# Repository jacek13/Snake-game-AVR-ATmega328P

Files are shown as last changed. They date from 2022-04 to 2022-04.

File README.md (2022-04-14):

# **Snake game on AVR**

The aim of my project was to create a device that allows you to play the popular game `"Snake"`. I completed the project as part of a university subject. While creating it, I used my original snake game written in C++ for Windows (graphics shown in the command line). I was prototyping the Arduino version. Then I rewritten the whole project into C language on the AVR microcontroller (ATmega328P). 

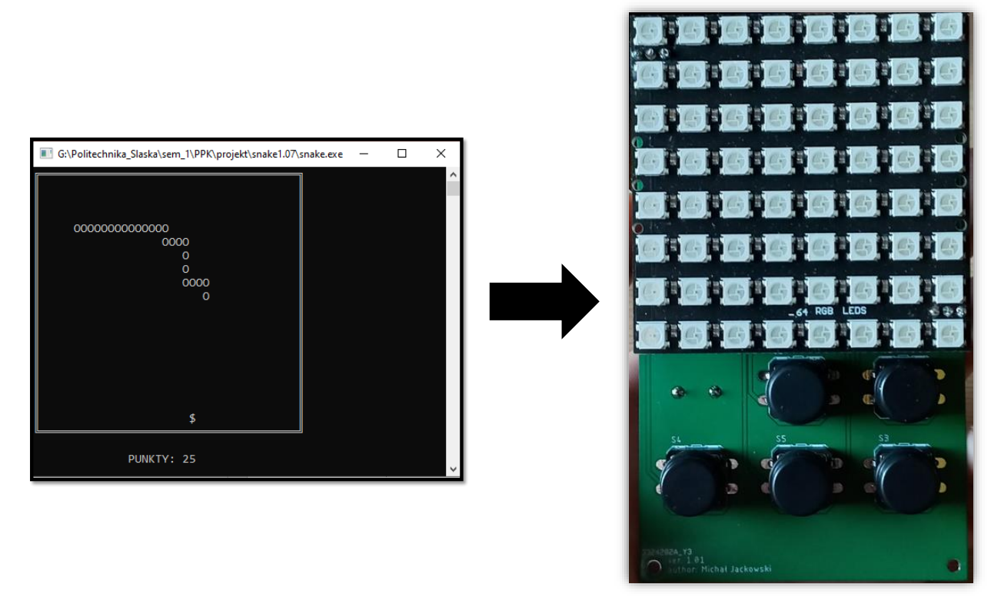
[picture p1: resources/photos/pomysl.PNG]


# **Game Demo**

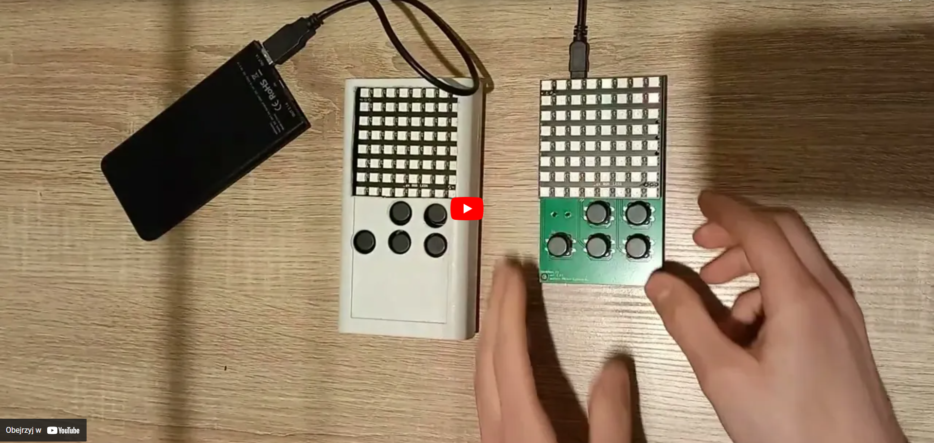
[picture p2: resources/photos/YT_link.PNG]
IMAGE_LINK (https://youtu.be/W63zcMBPLeU)


# **Elements used in the project:**
* RGB matrix 8 x 8 WS2812B
* 5 microswitches
* Buzzer HCM1206X
* ATmega328P
* USB as power supply
* custom board (All eagle files is in resources folder)
* necessary RC elements (all information about values is in the schematics)

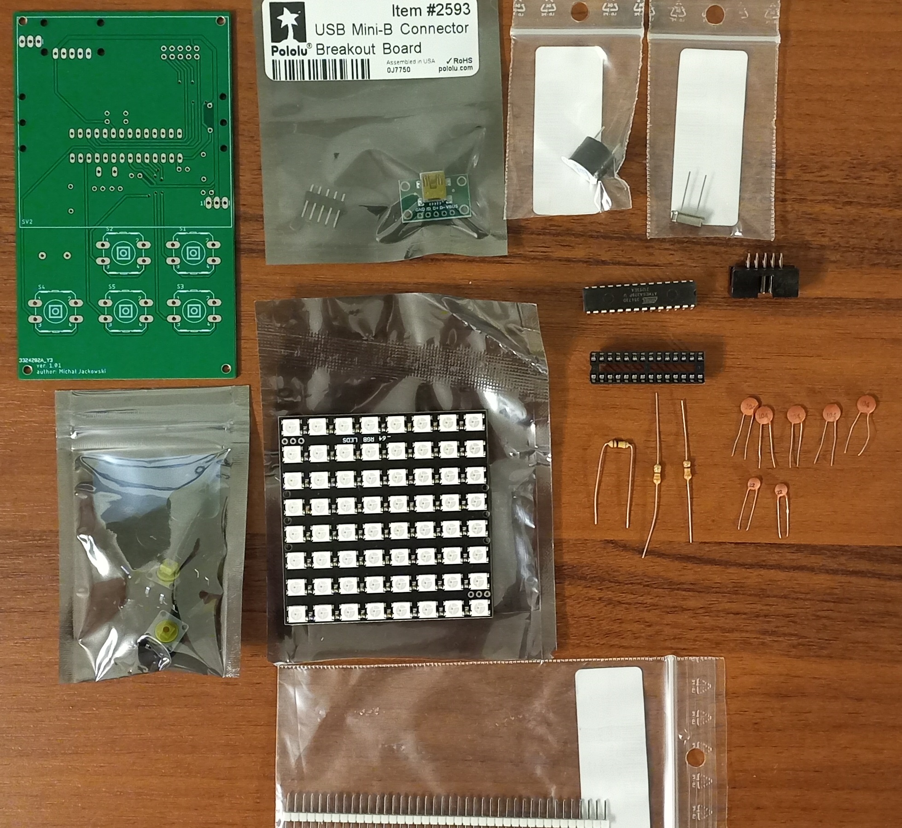
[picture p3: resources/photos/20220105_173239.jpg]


# **PCB**

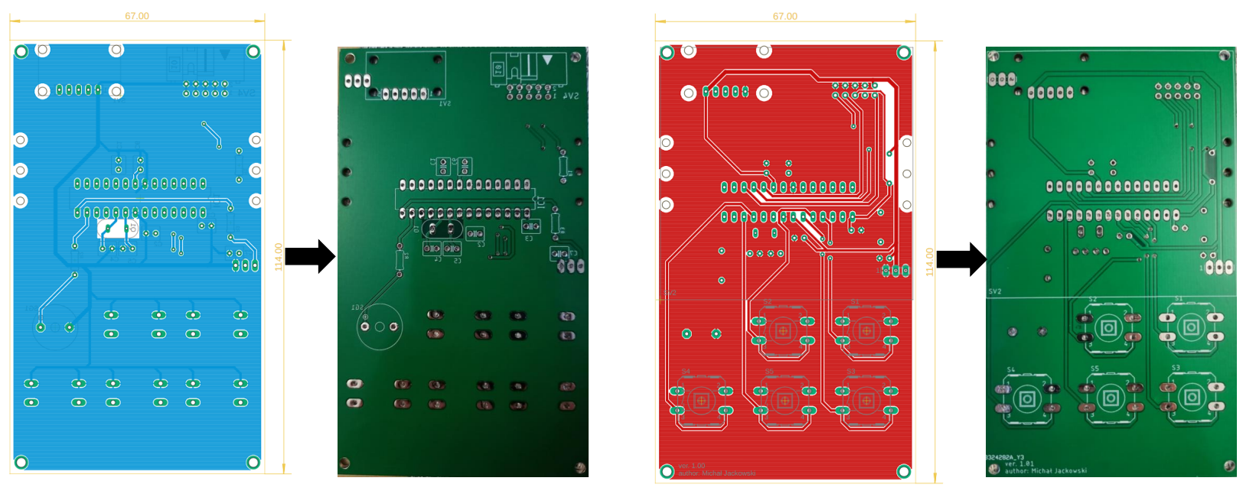
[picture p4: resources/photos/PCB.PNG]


# **IMPORTANT**

in the resources folder there are hex files for both versions of the project (Arduino and AVR). Please note that the AVR version only works for frequencies based on the internal RC oscillator (Set fuse bits on 8Mhz). The prototype version from arduino uses an external crystal oscillator (then you have to change the fuse bits to the external 16 MHz clock). This limitation is due to the [**`light_ws2812`**](https://github.com/cpldcpu/light_ws2812) library that I am using in the project.

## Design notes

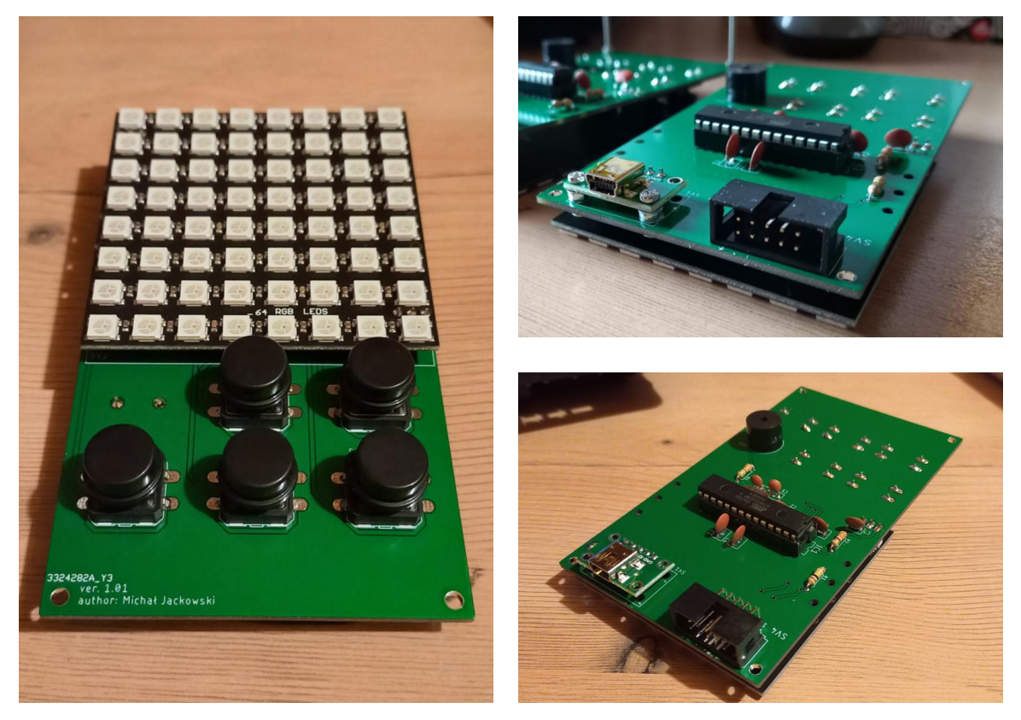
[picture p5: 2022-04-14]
resources/photos/kombinacja_zdjec.PNG

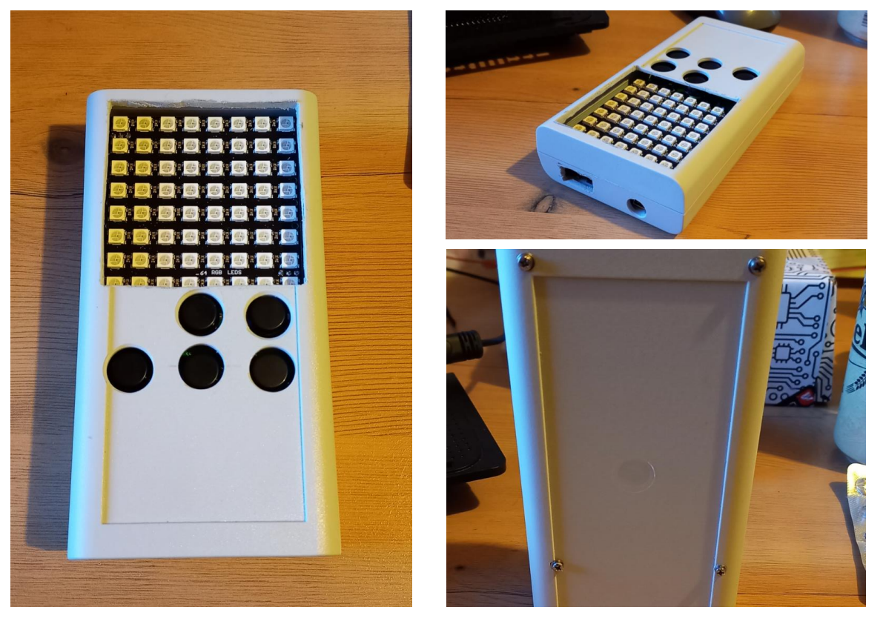
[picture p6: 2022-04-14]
resources/photos/kombinacja_zdjec_1.PNG

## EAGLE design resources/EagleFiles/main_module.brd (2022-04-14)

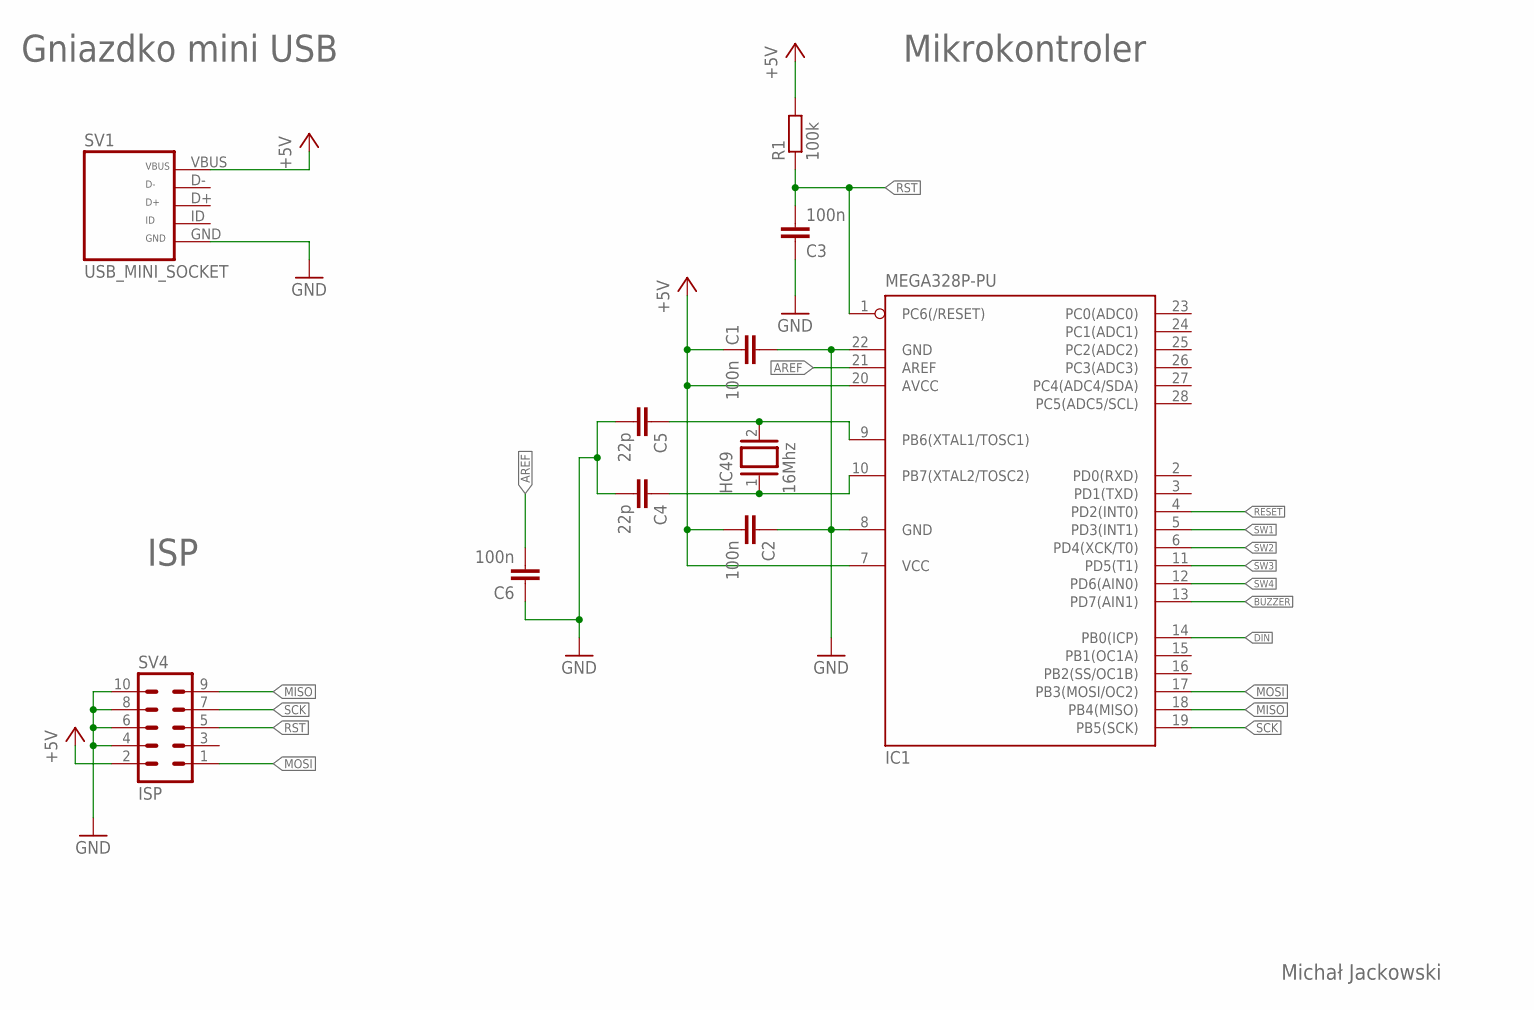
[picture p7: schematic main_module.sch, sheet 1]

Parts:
C1, C2, C3, C6: 100n; C025-040X050
C4, C5: 22p; C025-040X050
IC1: MEGA328P-PU; DIL28-3
Q1: 16Mhz; Q
R1: 100k; 0204/7
SV1: USB_MINI_SOCKET; FE05-1
SV4: ISP; ML10L

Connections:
+5V: C1.2, C2.2, IC1.7 (VCC), IC1.20 (AVCC), R1.2, SV1.VBUS, SV4.2; also elsewhere on the board
AREF: C6.2, IC1.21 (AREF)
BUZZER: IC1.13 (PD7(AIN1)); also elsewhere on the board
DIN: IC1.14 (PB0(ICP)); also elsewhere on the board
GND: C1.1, C2.1, C3.1, C4.2, C5.2, C6.1, IC1.8 (GND), IC1.22 (GND), SV1.GND, SV4.4, SV4.6, SV4.8, SV4.10; also elsewhere on the board
MISO: IC1.18 (PB4(MISO)), SV4.9
MOSI: IC1.17 (PB3(MOSI/OC2)), SV4.1
unnamed: C5.1, IC1.9 (PB6(XTAL1/TOSC1)), Q1.2
unnamed: C4.1, IC1.10 (PB7(XTAL2/TOSC2)), Q1.1
RESET: IC1.4 (PD2(INT0)); also elsewhere on the board
RST: C3.2, IC1.1 (PC6(/RESET)), R1.1, SV4.5
SCK: IC1.19 (PB5(SCK)), SV4.7
SW1: IC1.5 (PD3(INT1)); also elsewhere on the board
SW2: IC1.6 (PD4(XCK/T0)); also elsewhere on the board
SW3: IC1.11 (PD5(T1)); also elsewhere on the board
SW4: IC1.12 (PD6(AIN0)); also elsewhere on the board

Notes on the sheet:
Michał Jackowski
Gniazdko mini USB
ISP
Mikrokontroler

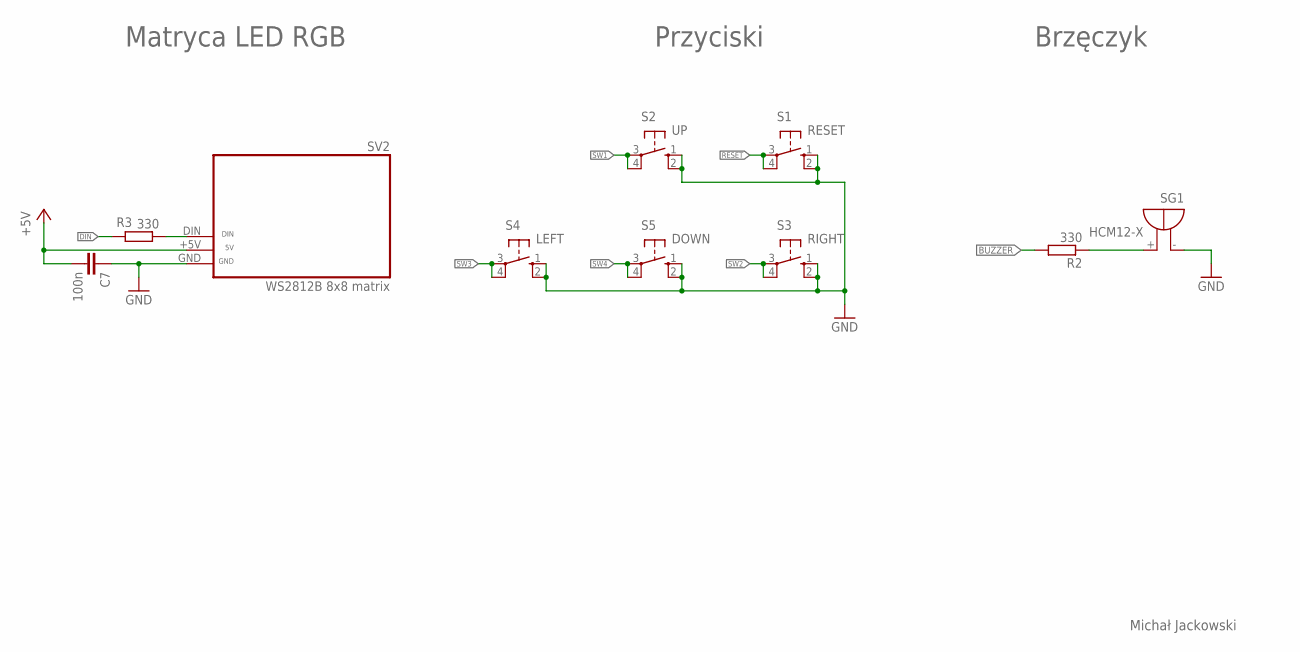
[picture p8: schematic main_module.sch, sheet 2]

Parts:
C7: 100n; C025-040X050
R2, R3: 330; 0204/7
S1: RESET; B3F-40XX
S2: UP; B3F-40XX
S3: RIGHT; B3F-40XX
S4: LEFT; B3F-40XX
S5: DOWN; B3F-40XX
SG1: HCM12-X; F/QMBIII
SV2: RGB_MATRIX_SOCKET; MA03-1

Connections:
+5V: C7.2, SV2.+5V (5V); also elsewhere on the board
BUZZER: R2.2; also elsewhere on the board
DIN: R3.2; also elsewhere on the board
GND: C7.1, S1.1 (S), S1.2 (S1), S2.1 (S), S2.2 (S1), S3.1 (S), S3.2 (S1), S4.1 (S), S4.2 (S1), S5.1 (S), S5.2 (S1), SG1.- (+), SV2.GND; also elsewhere on the board
unnamed: R2.1, SG1.+ (-)
unnamed: R3.1, SV2.DIN
RESET: S1.3, S1.4 (P1); also elsewhere on the board
SW1: S2.3, S2.4 (P1); also elsewhere on the board
SW2: S3.3, S3.4 (P1); also elsewhere on the board
SW3: S4.3, S4.4 (P1); also elsewhere on the board
SW4: S5.3, S5.4 (P1); also elsewhere on the board

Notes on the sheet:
Matryca LED RGB
Przyciski
Brzęczyk
Michał Jackowski

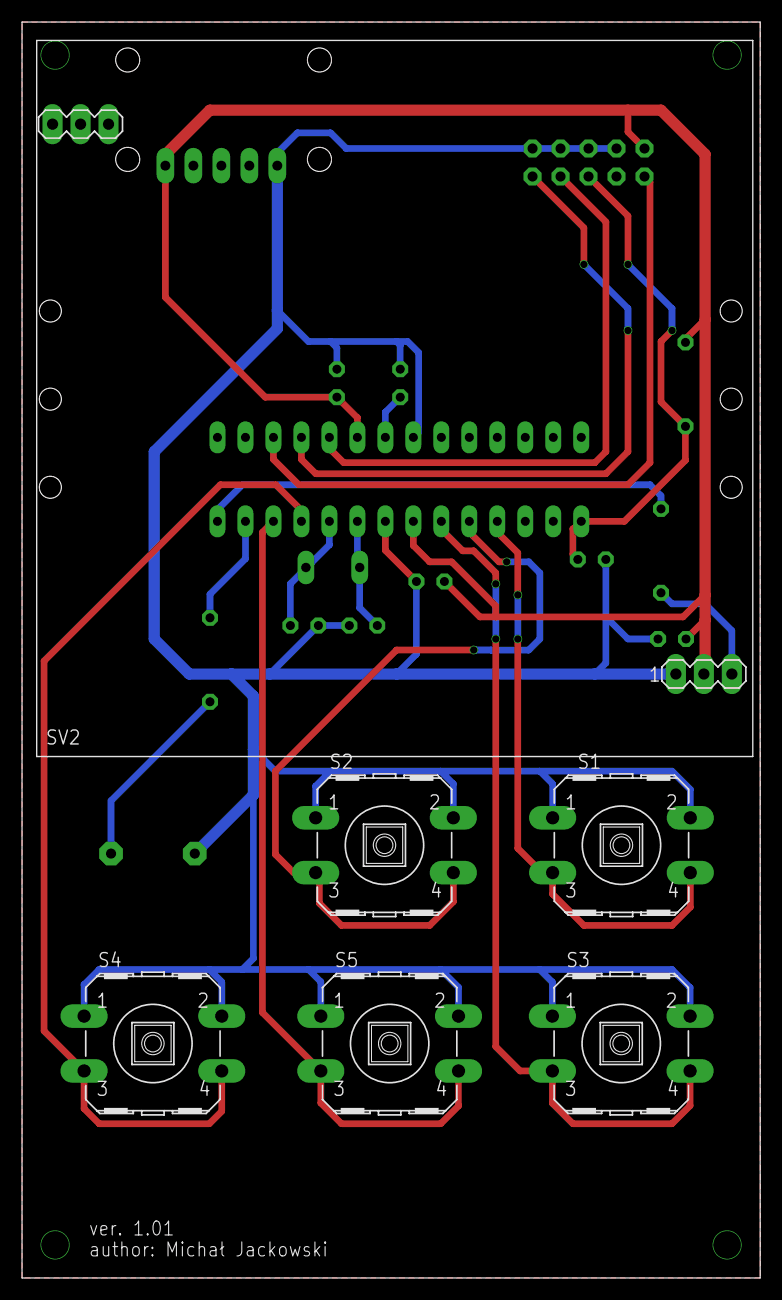
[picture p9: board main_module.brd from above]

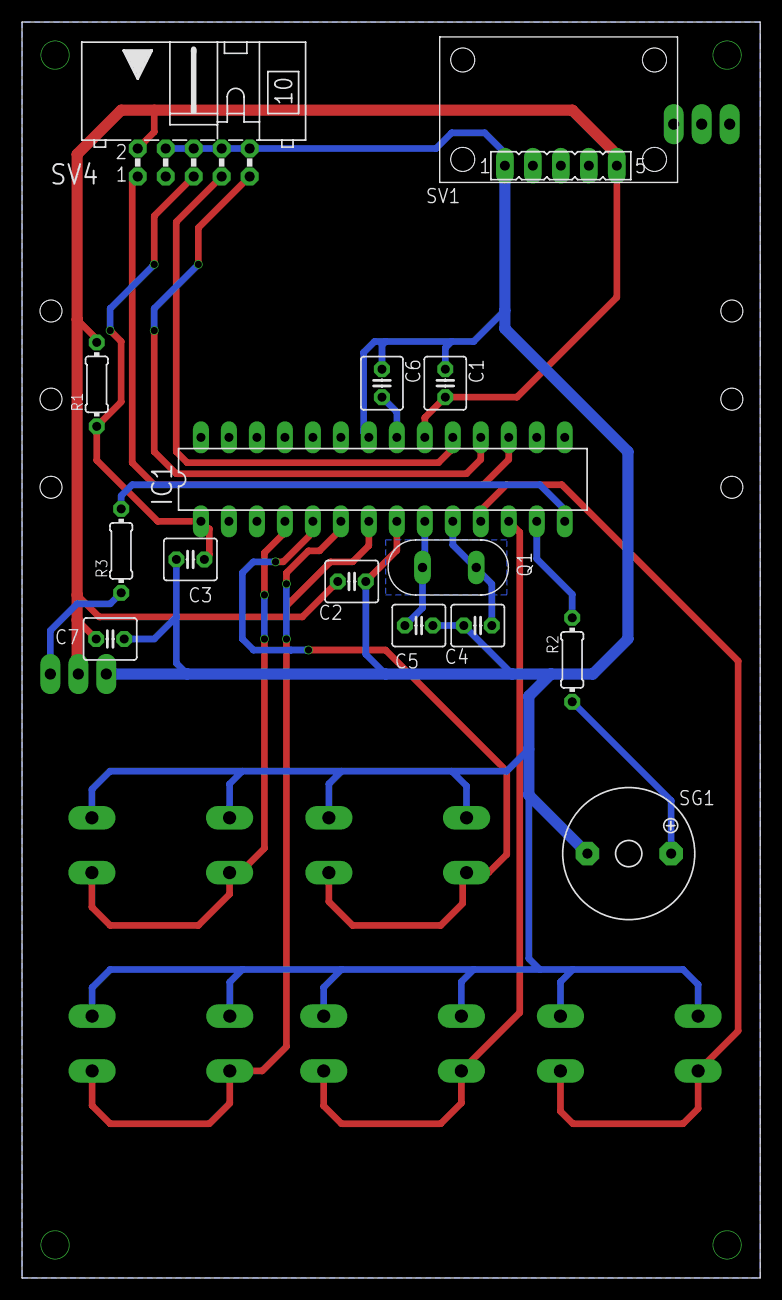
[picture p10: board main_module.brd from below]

Board: 2 copper layers, 67.0 x 114.0 mm, 21 parts (15 on the bottom side), 18 nets.

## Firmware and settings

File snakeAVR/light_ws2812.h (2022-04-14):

/*
 * light weight WS2812 lib include
 *
 * Version 2.3  - Nev 29th 2015
 * Author: Tim (cpldcpu@gmail.com) 
 *
 * Please do not change this file! All configuration is handled in "ws2812_config.h"
 *
 * License: GNU GPL v2+ (see License.txt)
 +
 */ 

#ifndef LIGHT_WS2812_H_
#define LIGHT_WS2812_H_

#include <avr/io.h>
#include <avr/interrupt.h>

///////////////////////////////////////////////////////////////////////
// Define Reset time in µs.
//
// This is the time the library spends waiting after writing the data.
//
// WS2813 needs 300 µs reset time
// WS2812 and clones only need 50 µs
//
///////////////////////////////////////////////////////////////////////
#if !defined(ws2812_resettime)
#define ws2812_resettime    300
#endif

///////////////////////////////////////////////////////////////////////
// Define I/O pin
///////////////////////////////////////////////////////////////////////
#if !defined(ws2812_port)
#define ws2812_port B   // Data port
#endif

#if !defined(ws2812_pin)
#define ws2812_pin  0   // Data out pin
#endif

/*
 *  Structure of the LED array
 *
 * cRGB:     RGB  for WS2812S/B/C/D, SK6812, SK6812Mini, SK6812WWA, APA104, APA106
 * cRGBW:    RGBW for SK6812RGBW
 */

struct cRGB  { uint8_t g; uint8_t r; uint8_t b; };
struct cRGBW { uint8_t g; uint8_t r; uint8_t b; uint8_t w;};



/* User Interface
 * 
 * Input:
 *         ledarray:           An array of GRB data describing the LED colors
 *         number_of_leds:     The number of LEDs to write
 *         pinmask (optional): Bitmask describing the output bin. e.g. _BV(PB0)
 *
 * The functions will perform the following actions:
 *         - Set the data-out pin as output
 *         - Send out the LED data 
 *         - Wait 50µs to reset the LEDs
 */

void ws2812_setleds     (struct cRGB  *ledarray, uint16_t number_of_leds);
void ws2812_setleds_pin (struct cRGB  *ledarray, uint16_t number_of_leds,uint8_t pinmask);
void ws2812_setleds_rgbw(struct cRGBW *ledarray, uint16_t number_of_leds);

/* 
 * Old interface / Internal functions
 *
 * The functions take a byte-array and send to the data output as WS2812 bitstream.
 * The length is the number of bytes to send - three per LED.
 */

void ws2812_sendarray     (uint8_t *array,uint16_t length);
void ws2812_sendarray_mask(uint8_t *array,uint16_t length, uint8_t pinmask);


/*
 * Internal defines
 */
#if !defined(CONCAT)
#define CONCAT(a, b)            a ## b
#endif

#if !defined(CONCAT_EXP)
#define CONCAT_EXP(a, b)   CONCAT(a, b)
#endif

#define ws2812_PORTREG  CONCAT_EXP(PORT,ws2812_port)
#define ws2812_DDRREG   CONCAT_EXP(DDR,ws2812_port)

#endif /* LIGHT_WS2812_H_ */
